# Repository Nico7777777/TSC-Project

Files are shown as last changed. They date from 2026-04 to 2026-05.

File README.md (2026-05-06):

# InkTime Smartwatch
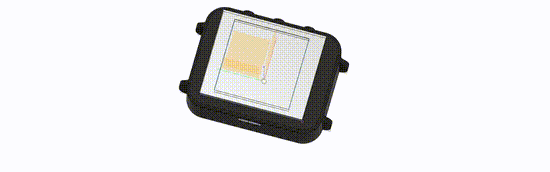
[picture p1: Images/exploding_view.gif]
Exploding View


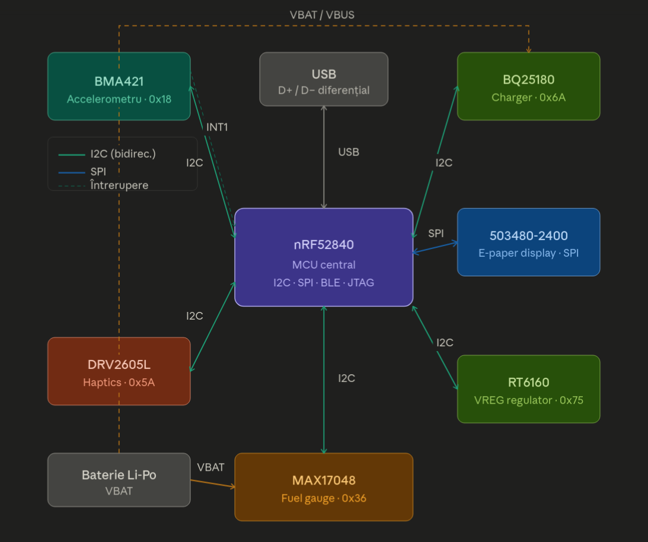
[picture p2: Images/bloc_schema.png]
Bloc Schema

### Main components:
<ol>
    <li><b>MCU</b></li>
        <i>component</i>: nFR52840-QIAA <br>
        <i>connectivity</i>: its mandatory connections for proper functioning are the VDD 
        and VDDH(for normal-voltage mode) and a VSS with pad exposure for 
        electrical connectivity testing <br>
        <i>placement</i>: the MCU is centered horizontally and vertically; additionally 
        it is equidistant to most ICs in order to optimize the signals and power train. 
        There are seldom unoptimised-length signal wires or wires on other layers
        optimized for both signal and power train to e
        <i>decoupling</i>: here we have 3 smaller capacitors for power decoupling 
        connected on pin DEC1(100nF to GND) and pins DEC4 & DEC6(1uF to GND) <br>
        <i>clock</i>: the clock  is determined as it follows: 32MHz between CX1/XC2 and 32.768KHz between XL1/XL2. The crystal oscillators were placed 
        as close as possible to the MCU
    <li><b>Accelerometer</b></li>
        <i>component</i>: BMA421
        <i>connectivity:</i> connected on the I<sup>2</sup>C bus to the MCU; has 
        low power mode logic for embedded systems power usage; thus, it wakes 
        when pin IN1 triggers as to eliminate busy waiting on signal; additionally 
        there's INT2 pin for debugging that may be consulted furthermore via the JTAG
    <li><b>Haptics</b></li>
        <i>component:</i>: DRV2605L
        <i>placement</i>: as to avoid vibrations to trigger walking mode, a key trait 
        taken into consideration at PCB design stage was the distance between the haptics
        driver and accelerometer which is approximately half of the board's width between 
        the two of them. 
        <i>power stage:</i> it is following the Richtek recommended values 
        inductor/capacitor: 0.47uH, multi-22uF input and 10uF output
    <li><b>Fuel Gauge</b></li>
        <i>component</i>: the MAX17048
        <i>placement</i>: in the middle-bottom part of the board
        <i>functionality</i>: it is meant to trigger on ALRT through interrupts 
        when the functioning voltage should lower to VDD_3V3 value as for battery saving
    <li><b>E-paper Display</b></li>
        <i>component</i>: 503480-2400
        <i>connectivity</i>: unlike points 2, 3 and 4, it is connected via SPI; 
        obviously, the display cannot be multiplexed with other IC devices, duhhhh.
        <i>placement</i>: it is placed on the very right side of the board; for low
        latency I chose to wire the SPI interface via the power layer for a resonably
        short distance to the MCU pins.
</ol>

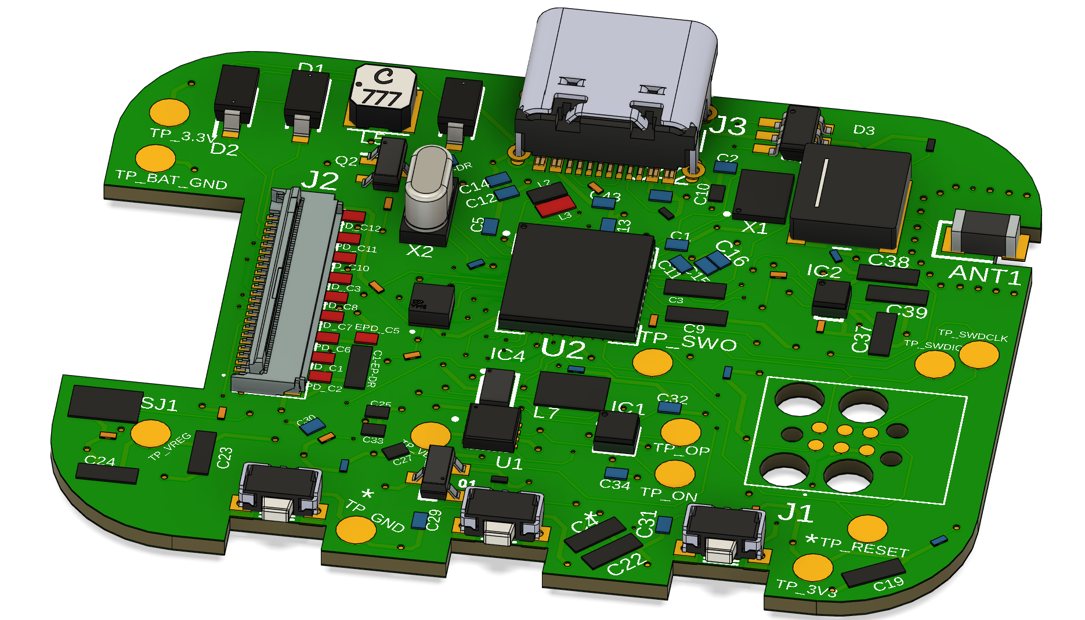
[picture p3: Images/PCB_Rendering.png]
Preview


### USB
<i>placement</i>: the usb is placed on the top side of the board, accurately snaped to the
watch case slot for the USB connection. <br>
<i>wiring</i>: for the differential wires of the USB, a very accurate and exhaustive routing has been 
undergone. Case in point, D- and D+ have been 95% equidistant and perserve the length 
and width all way long.

### I<sup>2</sup>C address mapping
Address mapping(7-bit addresses) on the I<sup>2</sup>C interface:
<ul>
<li>BMA421: 0x18 - accelerometer</li>
<li>MAX17048: 0x36 - </li>
<li>DRV2605L: 0x5A - haptics driver and ERM motor</li>
<li>BQ25180: 0x6A</li>
<li>RT6160: 0x75</li>
</ul>

### PCB Layout
<i>layers</I>: 4-layers for RF performance and power integrity
<ol>
<li> Signals - most of the signal are connected here; also few components are tied
together group by 2 or 3 on top before via stitching to the GND or power.</li>
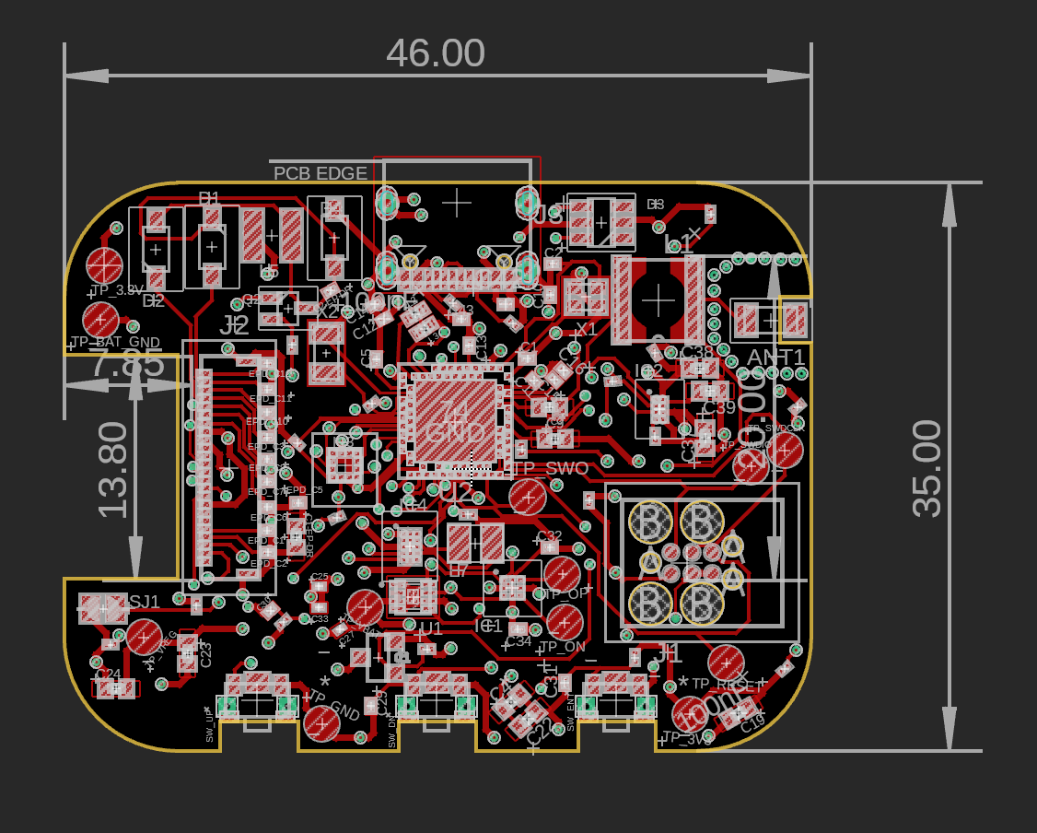
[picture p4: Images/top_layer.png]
1.Top layer
<br><br>

<li> GND  - for preventing energy spikes at charging/powering decoupling capacitors 
have been spread all across the top layer tightly wired to the ICs</li>
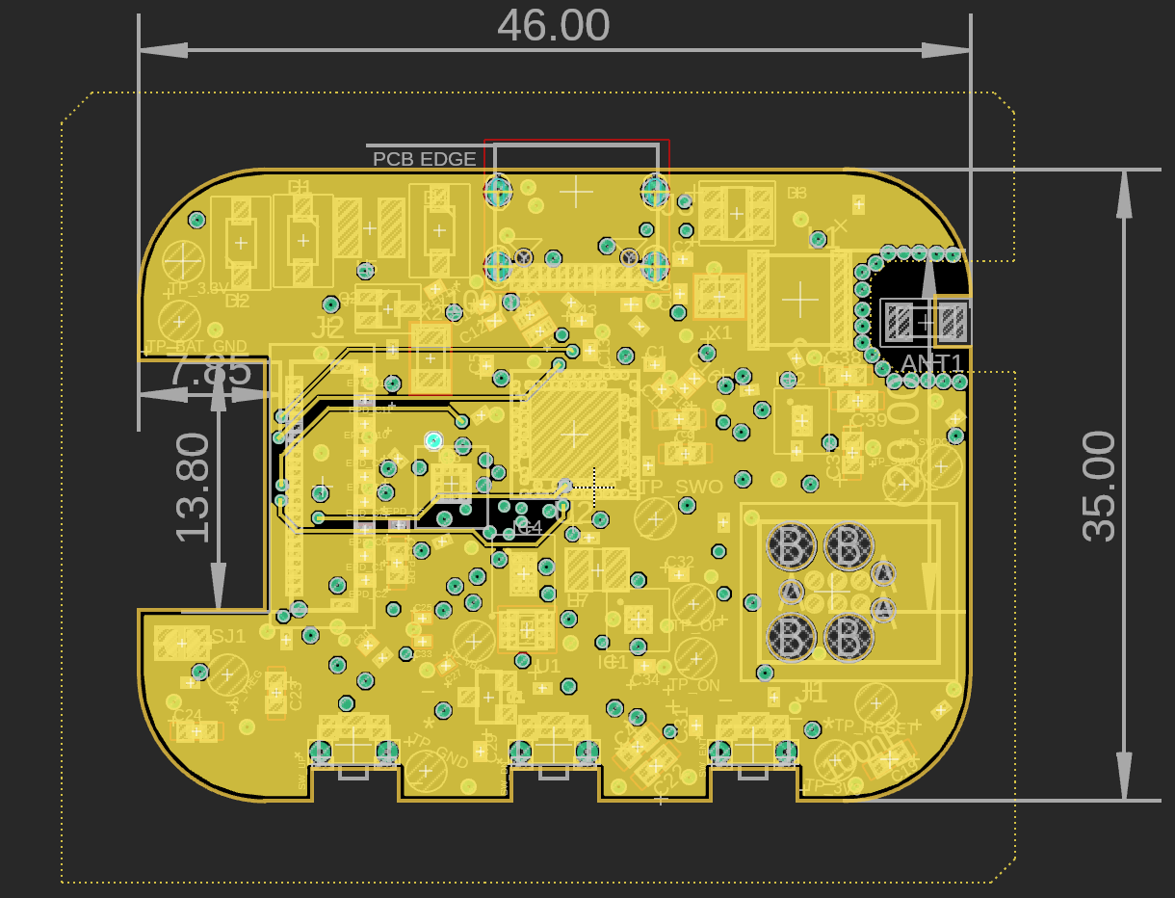
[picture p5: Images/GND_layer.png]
4.Bottom layer
<br><br>

<li> Power - main copper layer is tied to 3V3 signal; other values wired on this 
layer include as well: EPD_3V3, VREG, VBAT, VBUS; also P0.13 and p0.14 signal 
pins of the MCU are wired on this layer for PCB design simplicity reasons</li>
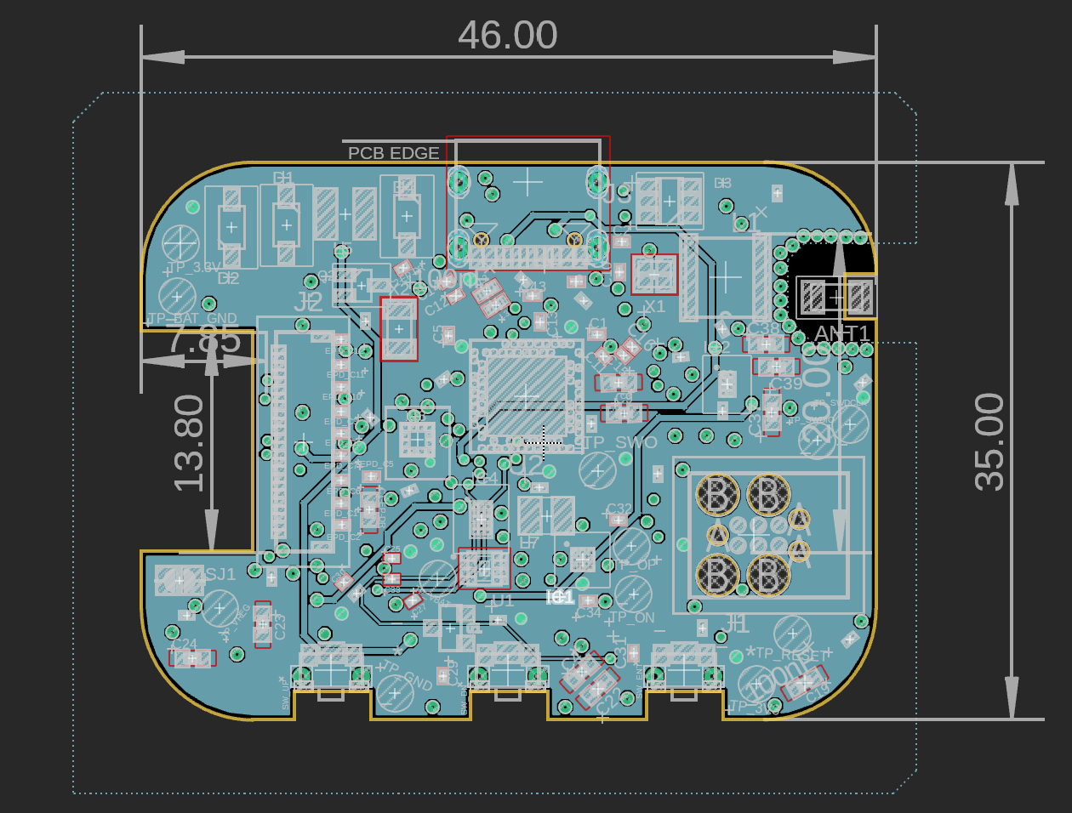
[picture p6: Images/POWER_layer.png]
3. Power layer
<br><br>

<li> Signals - plenty of I<sup>2</sup>C interface, charger connectivity and USB data 
are the main actors of the fourth layer out of the PCB</li>
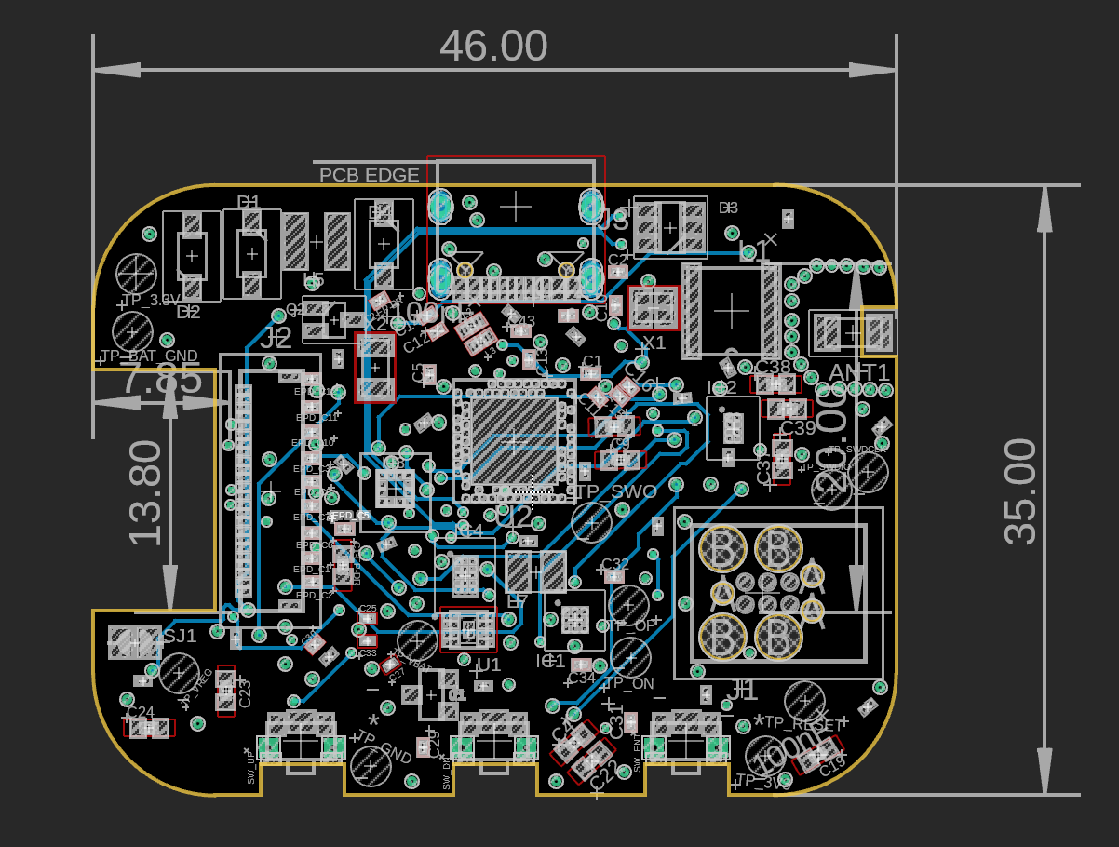
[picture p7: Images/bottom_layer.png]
4.Bottom layer

</ol>

### RF functioning
The PCB is cropped on the upper part of the right side as for creating a slot for the 
antenna's pad. The copper layers for GND and POWER and cropper as well a few milimiters 
margin from the whole antenna. Moreover, vias have been placed all around the antenna. The noise and interference are preempted as possible from the footprint stage and 
placement.

### Software Stack
Recommended layers:
<pre>
1. Real-Time Operating-System(RTOS) for low latency<br>
    | providing <br>
    | <br>
    ----> 2. Drivers for I<sup>2</sup>C/SPI/GPIO <br>
            | providing <br>
            | <br>
            ----> 3. Services as power mng, BLE/UI, clocks 
                    and interrupts and refreshing/ghosting
</pre>
Suggestion: Zephyr OS for BLE maturity or any other monolithic kernels OSes suitable
for embedded devices

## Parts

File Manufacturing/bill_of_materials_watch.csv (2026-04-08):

Reference Designators | Quantity | Description | Package | Value | Manufacturer | Manufacturer Part Number | Vendor | Vendor Part Number | Top/Bottom
 | 1 | PCB Board | Board
ANT1 | 1 | Antennas 2.45GHz ANTENNA | 2450AT18B100E_ANTC3216X140N | 2450AT18B100E |  |  |  |  | Top
C1, C2 | 2 | Generic chip capacitor | NORDIC_NRF_3_RESC0201_L | 12pF |  |  |  |  | Top
C1-EP-DR, C24, C39 | 3 | CAPACITOR, European symbol | ESP32_WROVER_EAGLE-LTSPICE_C0402 | 10uF |  |  |  |  | Top
C2-EP-DR | 1 | Generic chip capacitor | NORDIC_NRF_3_RESC0201_L | 4.7uF/25V |  |  |  |  | Top
C3, C4 | 2 | CAPACITOR, European symbol | ESP32_WROVER_EAGLE-LTSPICE_C0402 | 1pF |  |  |  |  | Top
C5 | 1 | Generic chip capacitor | NORDIC_NRF_3_RESC0201_L | 100nF |  |  |  |  | Top
C6, C20, C21 | 3 | Check availability | GRM011R60J152KE01L_1_0201 | 4.7uF |  |  |  |  | Top
C7, C8 | 2 | Check availability | GRM011R60J152KE01L_1_0201 | 100nF |  |  |  |  | Top
C9 | 1 | CAPACITOR, European symbol | ESP32_WROVER_EAGLE-LTSPICE_C0402 | 820pF N.C. |  |  |  |  | Top
C10, C13 | 2 | Generic chip capacitor | NORDIC_NRF_3_RESC0201_L | N.C. |  |  |  |  | Top
C11 | 1 | Generic chip capacitor | NORDIC_NRF_3_RESC0201_L | 100pF |  |  |  |  | Top
C12 | 1 | Generic chip capacitor | NORDIC_NRF_3_RESC0201_L |  |  |  |  |  | Top
C14, C43 | 2 | Generic chip capacitor | NORDIC_NRF_3_RESC0201_L | 4.7uF |  |  |  |  | Top
C15 | 1 | Generic chip capacitor | NORDIC_NRF_3_RESC0201_L | 1.0uF |  |  |  |  | Top
C16 | 1 | Generic chip capacitor | NORDIC_NRF_3_RESC0201_L | 47nF |  |  |  |  | Top
C17, C18 | 2 | Check availability | GRM011R60J152KE01L_1_0201 | 12pF |  |  |  |  | Top
C19 | 1 | CAPACITOR, European symbol | ESP32_WROVER_EAGLE-LTSPICE_C0402 |  |  |  |  |  | Top
C22 | 1 | CAPACITOR, European symbol | ESP32_WROVER_EAGLE-LTSPICE_C0402 | N.C. |  |  |  |  | Top
C23 | 1 | CAPACITOR, European symbol | ESP32_WROVER_EAGLE-LTSPICE_C0402 | 0.1uF |  |  |  |  | Top
C25, C33 | 2 | Check availability | CAPC0201X13N | 22uF |  |  |  |  | Top
C27 | 1 | Check availability | CAPC0201X13N | 0.1uF |  |  |  |  | Top
C29, C30, C31, C32 | 4 | Generic chip capacitor | NORDIC_NRF_3_RESC0201_L | 1uF |  |  |  |  | Top
C34, C42 | 2 | Generic chip capacitor | NORDIC_NRF_3_RESC0201_L | 0.1uF |  |  |  |  | Top
C37, C38 | 2 | CAPACITOR, European symbol | ESP32_WROVER_EAGLE-LTSPICE_C0402 | 1uF |  |  |  |  | Top
D1, D2, D4 | 3 | ON SEMICONDUCTOR - MBR0530 - DIODE, SCHOTTKY, 0.5A, 30V, SOD-123 | SOD3716X135N | MBR0530 |  |  |  |  | Top
D3 | 1 | Low Cap. ESD Protection Auto SOT-23-6 STMicroelectronics USBLC6-2SC6Y, Dual Uni-Directional TVS Diode Array, 6-Pin SOT-23 | SOT95P280X145-6N | USBLC6-2SC6Y |  |  |  |  | Top
EPD_C1, EPD_C2, EPD_C3, EPD_C5, EPD_C6, EPD_C7, EPD_C8, EPD_C10, EPD_C11, EPD_C12 | 10 | Generic chip capacitor | NORDIC_NRF_3_RESC0201_L | 1uF/50V |  |  |  |  | Top
IC1 | 1 | Haptic Driver for ERM/LRA with Built-In Library and Smart Loop Architecture | DRV2605YZFR_BGA9C50P3X3_144X144X62 | DRV2605YZFR |  |  |  |  | Top
IC2 | 1 | Charger IC Lithium Ion/Polymer, Lithium Iron Phosphate 8-DSBGA (1.6x1.1) | BQ25180YBGR_BGA8C40P2X4_100X155X50 | BQ25180YBGR |  |  |  |  | Top
IC3 | 1 | Accelerometers Triaxial low-g 12bit Acceleration Sensor | BMA423_BMA423 | BMA423 |  |  |  |  | Top
IC4 | 1 | Buck-Boost Regulator Positive Output Step-Up/Step-Down I2C DC-DC Controller IC 15-WL-CSP (BSC) (1.4x2.3) | RT6160AWSC_BGA15C40P3X5_140X230X60 | RT6160AWSC |  |  |  |  | Top
J1 | 1 | CABLE ADAPTER 6 POS | TC2030-IDC_TC2030IDC | TC2030-IDC |  |  |  |  | Top
J2 | 1 | FFC & FPC Connectors 0.5mm FPC RA SMT Dual Contact 24Ckt | 503480-2400_5034802400 | 503480-2400 |  |  |  |  | Top
J3 | 1 | Check availability | KINGHELM_KH-TYPE-C-16P | KH-TYPE-C-16P |  |  |  |  | Top
L1 | 1 |  | ESP32_C6_LIBRARY_2_IND_4828-WE-TPC_WRE | 3.9nH |  |  |  |  | Top
L2 | 1 | Generic chip inductor | NORDIC_NRF_2_RESC0402_L | 10uH |  |  |  |  | Top
L3 | 1 | Generic chip inductor | NORDIC_NRF_2_RESC0402_L | 15nH |  |  |  |  | Top
L5 | 1 | Inductor Fixed - Popular Parts | LPS3015 | 68uH | Coilcraft | LPS3015-222MRC |  |  | Top
L7 | 1 | SMD / SMT Inductors (Coils), L=0.47?H, L x W x T : | MLP2016SR47MT0S1_INDC2016X100N | FTC252012SR47MBCA |  |  |  |  | Top
Q1 | 1 | P-channel MOSFETs | ESP32_WROVER_SPARKFUN-DISCRETESEMI_SOT23-3 | 20V/4.2A/52mΩ/1.4W |  |  |  |  | Top
Q2 | 1 | MOSFET N-Ch 30V 1.5A TrenchFET SC70 Vishay Si1308EDL-T1-GE3 N-channel MOSFET Transistor, 1.5 A, 30 V, 3-Pin SC-70 | SOT65P210X110-3N | SI1308EDL-T1-GE3 |  |  |  |  | Top
R_TYPE_SEL | 1 | 7.68k 0201 Thin Film Surface Mount Fixed Resistor +/-0.5% 0.031W CPF0201D7K68C1 | CPF0201D7K68C1_0201 | 2.2 |  |  |  |  | Top
R1_EP_DR | 1 | 7.68k 0201 Thin Film Surface Mount Fixed Resistor +/-0.5% 0.031W CPF0201D7K68C1 | CPF0201D7K68C1_0201 | 0.47 |  |  |  |  | Top
R1_EP_DR1, R5, R8, R11 | 4 | 7.68k 0201 Thin Film Surface Mount Fixed Resistor +/-0.5% 0.031W CPF0201D7K68C1 | CPF0201D7K68C1_0201 | 10k |  |  |  |  | Top
R1_USB | 1 | 7.68k 0201 Thin Film Surface Mount Fixed Resistor +/-0.5% 0.031W CPF0201D7K68C1 | R0201 | 5K1 |  |  |  |  | Top
R2, R4, R7 | 3 | 7.68k 0201 Thin Film Surface Mount Fixed Resistor +/-0.5% 0.031W CPF0201D7K68C1 | CPF0201D7K68C1_0201 | 0 |  |  |  |  | Top
R2_USB | 1 | 7.68k 0201 Thin Film Surface Mount Fixed Resistor +/-0.5% 0.031W CPF0201D7K68C1 | CPF0201D7K68C1_0201 | 5K1 |  |  |  |  | Top
R9, R10 | 2 | 7.68k 0201 Thin Film Surface Mount Fixed Resistor +/-0.5% 0.031W CPF0201D7K68C1 | CPF0201D7K68C1_0201 | 10K |  |  |  |  | Top
SJ1 | 1 | SMD solder JUMPER | JUMPER_SJ |  |  |  |  |  | Top
SW_DN, SW_ENT, SW_UP | 3 |  | SW_EVP-AKE31A_PAN | 2025-10-22_07-23-44_LIBRARY_EVP-AKE31ASW_EVP-AKE31A_PAN |  |  |  |  | Top
TP_3.3V, TP_3V3, TP_BAT_GND, TP_GND, TP_ON, TP_OP, TP_RESET, TP_SWDCLK, TP_SWDIO, TP_SWO, TP_VBAT, TP_VREG | 12 | Test pad | HECTOR_WATCH_1_TP20R | HECTOR_WATCH_1_TPTP20R |  |  |  |  | Top
U1 | 1 | Check availability | SON50P200X200X80-9N | MAX17048G+T10 |  |  |  |  | Top
U2 | 1 | Bluetooth®5 IEEE 802.15.4-2006 2.4 GHz transceiver - SoC | NRF52840-QIAA | NRF52840-QIAA-R | Nordic Semiconductor ASA | NRF52840-QIAA-R |  |  | Top
X1 | 1 |  | NORDIC_NRF_BT-XTAL_2016_N | 32MHz |  |  |  |  | Top
X2 | 1 |  | NORDIC_NRF_1_XTAL_3215_N | 32.768KHz |  |  |  |  | Top

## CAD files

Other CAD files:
Mechanical/InkTime.f3d
Mechanical/InkTime_case_assembly.f3z

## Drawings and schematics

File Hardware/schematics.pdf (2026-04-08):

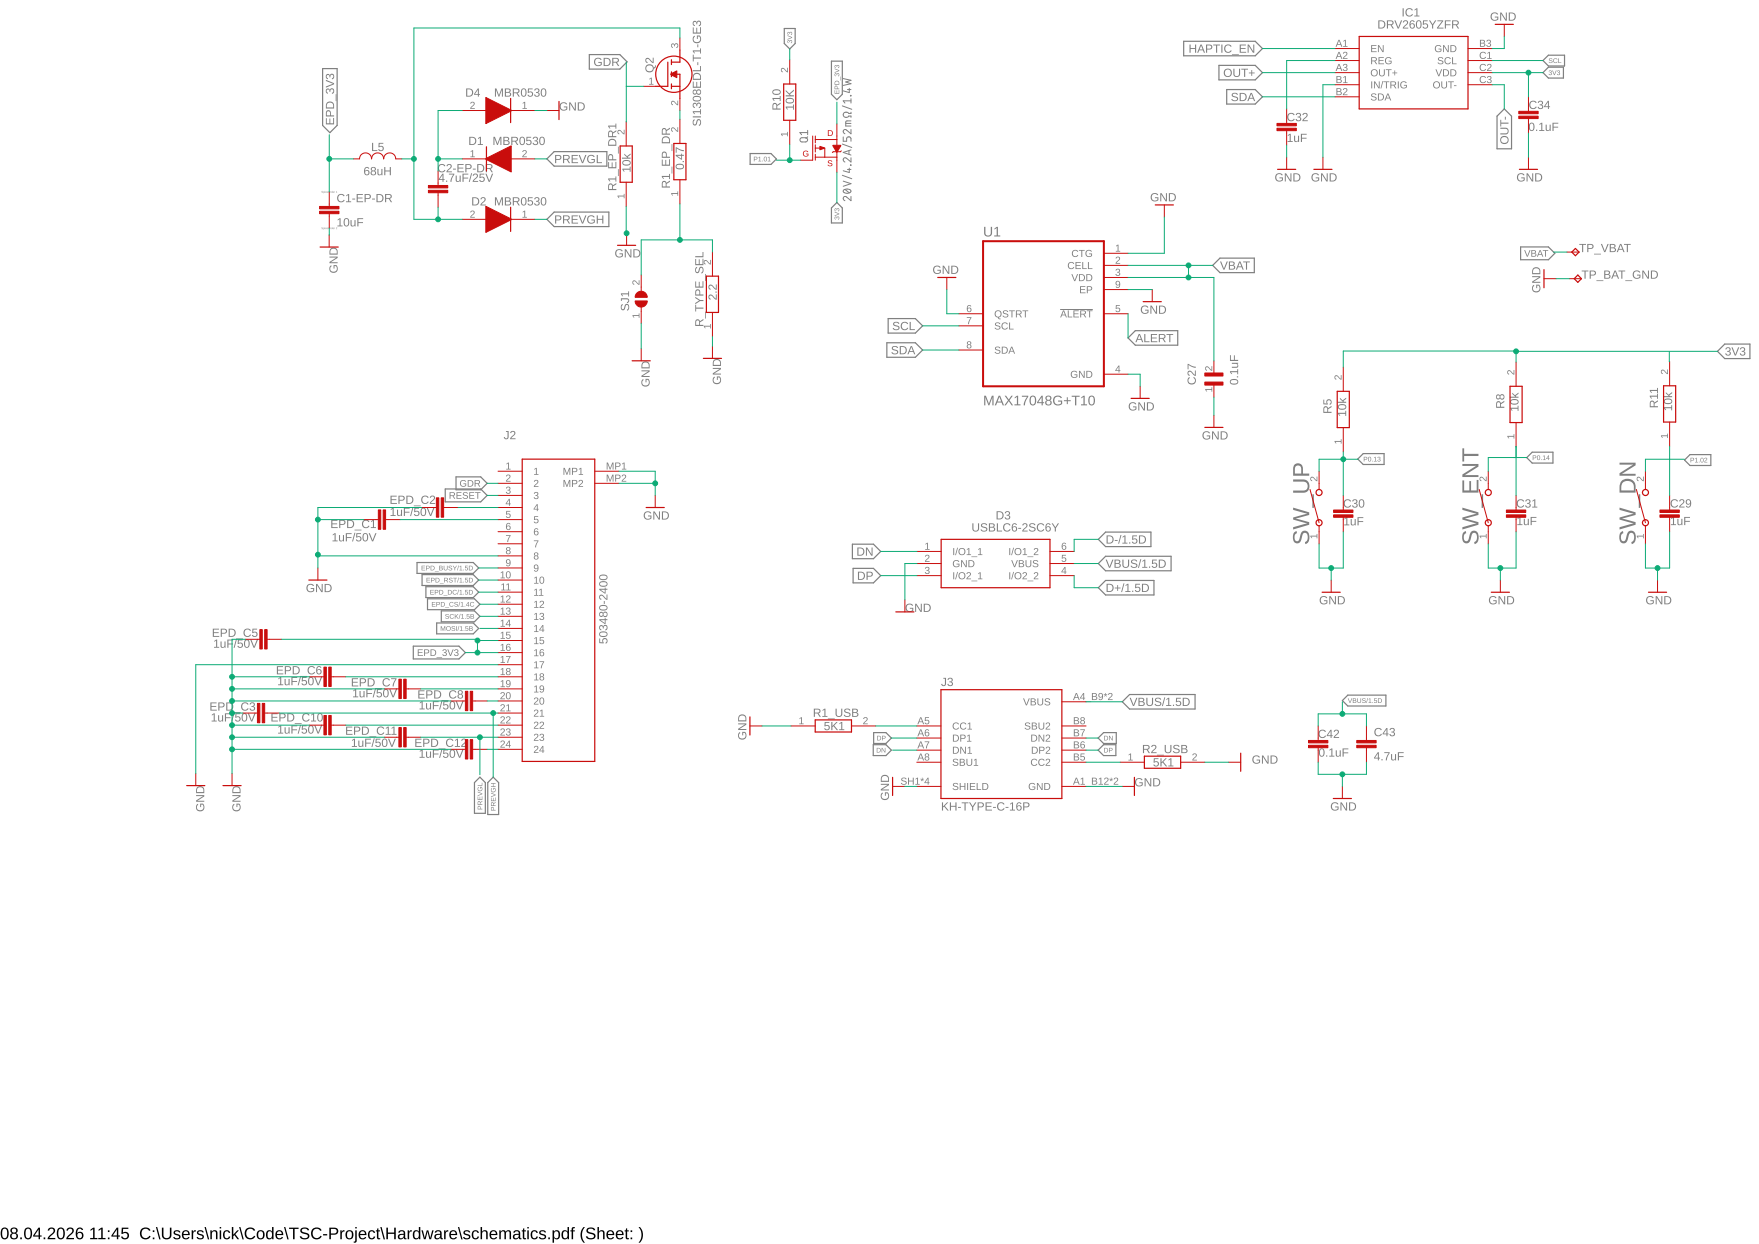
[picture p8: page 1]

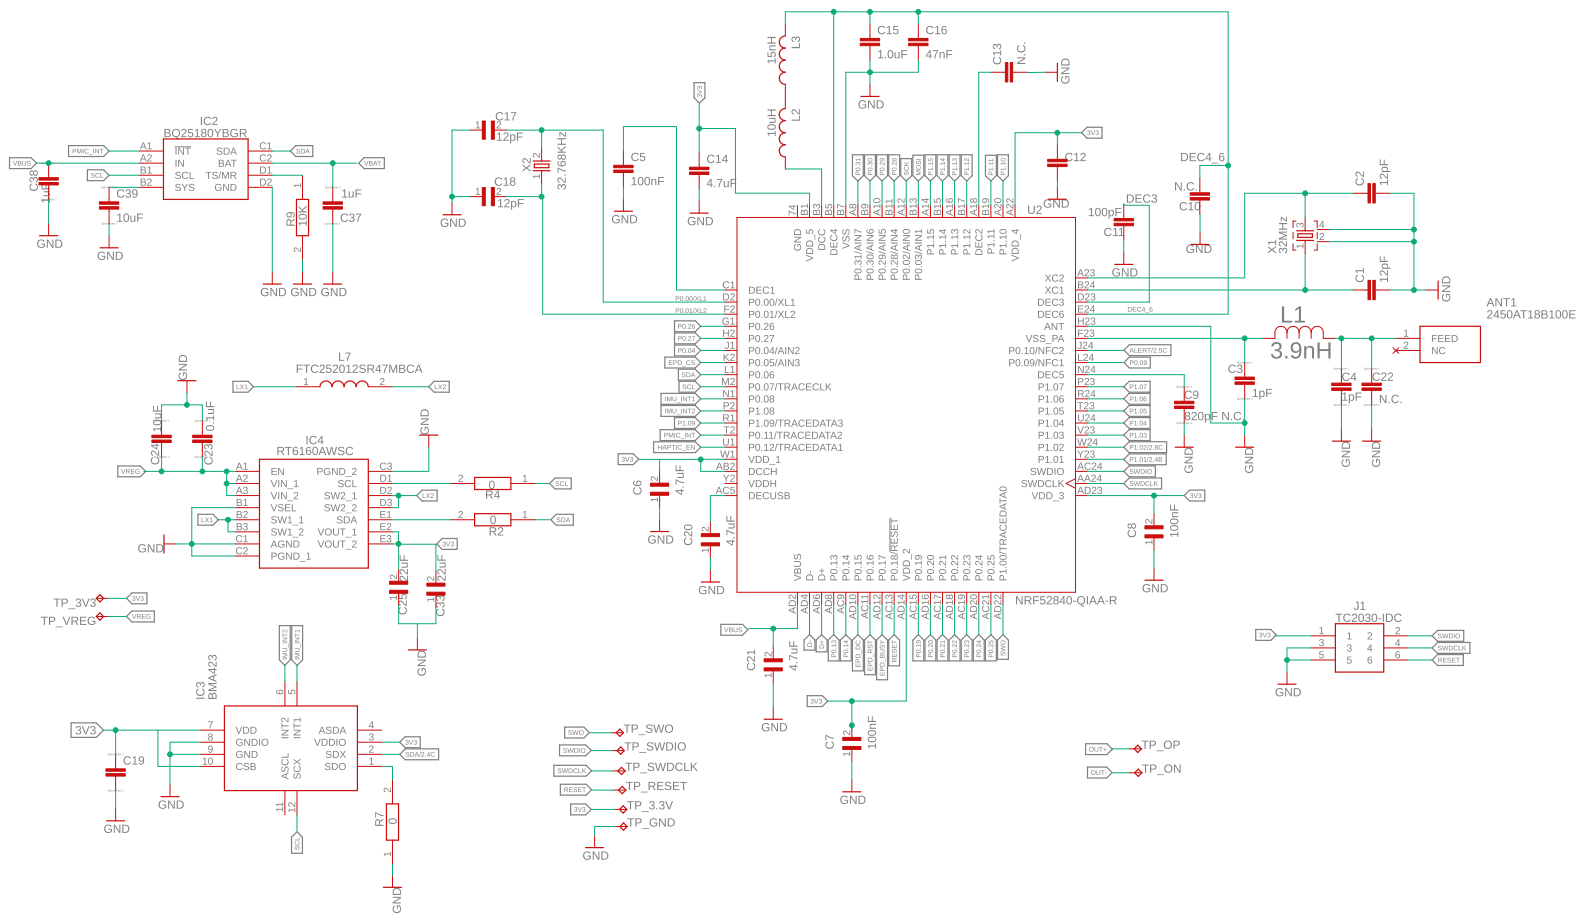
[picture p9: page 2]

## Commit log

2026-04-08 Manufacturing files added
    [PnP_InkTime_front.csv, bill_of_materials_watch.csv]
2026-04-10 Mechanical video description and f3z files
    [InkTime.f3d]
2026-04-21 deleted old files
    [PnP_InkTime_front.csv]
2026-04-21 new Pick&Place and 3D_Model
    [InkTime.f3d]
2026-04-21 new 3d
    [InkTime_case_assembly.f3z]
